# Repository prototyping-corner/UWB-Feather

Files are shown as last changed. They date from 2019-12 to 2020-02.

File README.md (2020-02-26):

# UWB Feather
  
OSHWA  

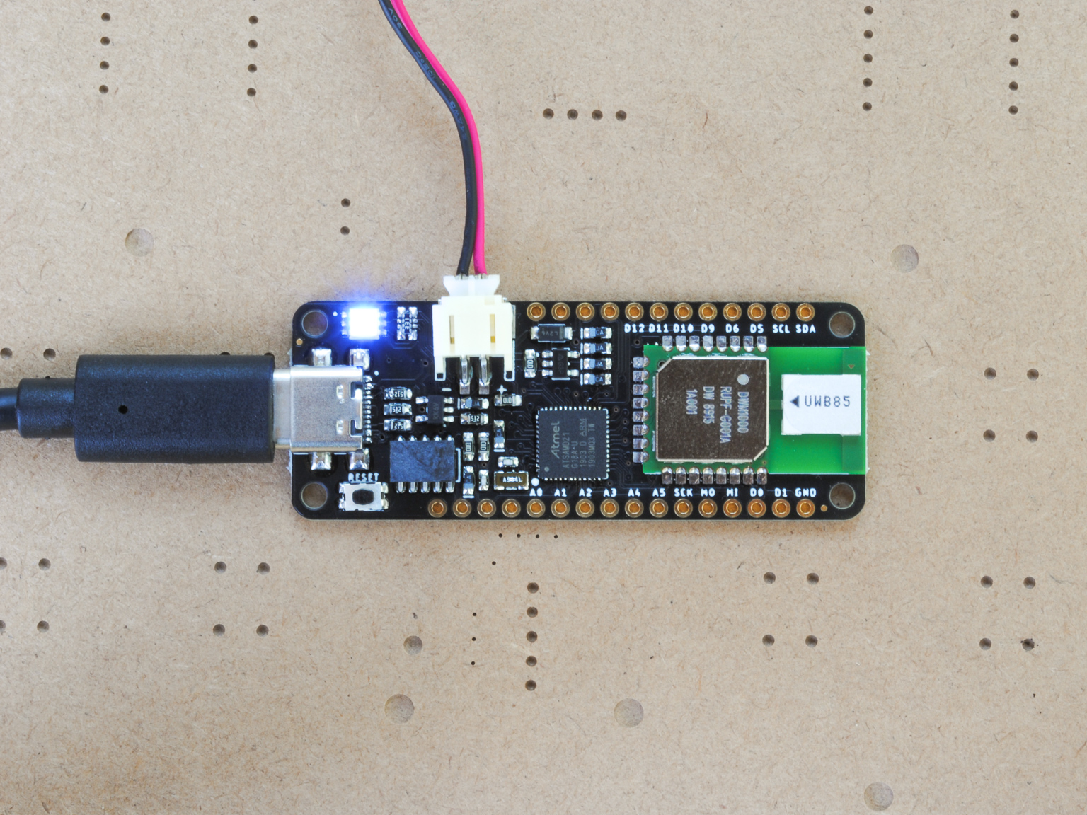
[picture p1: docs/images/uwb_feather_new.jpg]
Boards


The Ultra-WideBand Feather incorporates the Decawave DWM1000 module and an ATSAMD21 ARM Cortex M0 into the Adafruit feather form-factor. The DWM1000 module is an IEEE802.15.4-2011 UWB compliant wireless module capable of precision indoor positioning and high data rates, making this board perfect for robotics projects where localization is required.  

For full project details and documentation visit [prototypingcorner.io/projects/uwb-feather](prototypingcorner.io/projects/uwb-feather).

## Hardware
Licensed under the CERN OHL v1.2.  

Top  
Bottom  

## Firmware
Firmware providing in this repository is for testing the DWM1000 module and utilizes the [thotro/arduino-dw1000](https://github.com/thotro/arduino-dw1000) library. As this repository is no longer actively maintained, future development will focus on a new library.

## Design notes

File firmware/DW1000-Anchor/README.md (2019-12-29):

# DW1000 Anchor
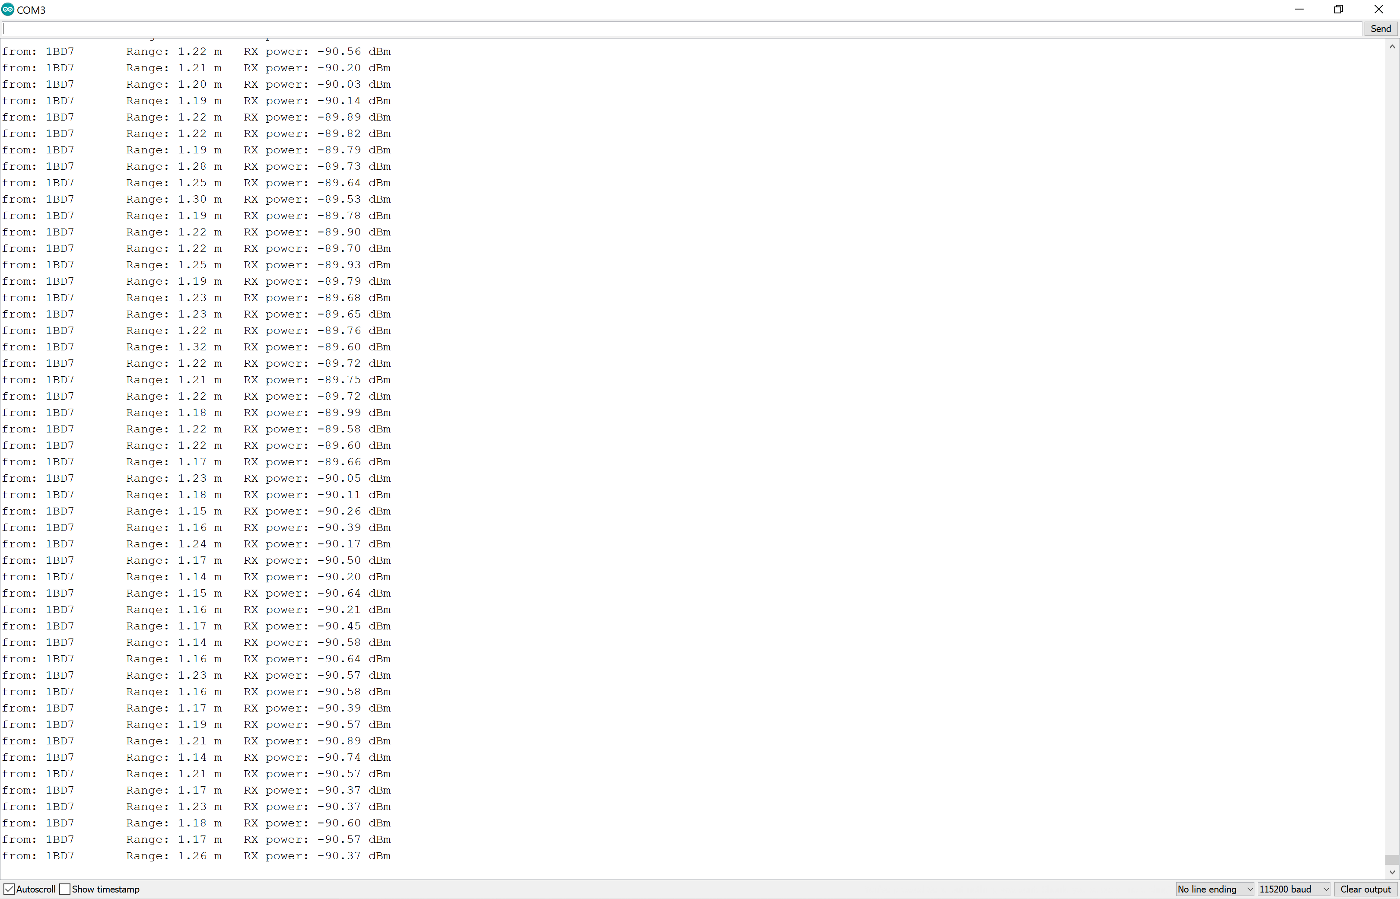
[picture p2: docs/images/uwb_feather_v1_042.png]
Ranging screenshot


Simple anchor mode for testing DWM1000 module. 
See [thotro/arduino-dw1000/examples/DW1000Ranging_TAG](https://github.com/thotro/arduino-dw1000/blob/master/examples/DW1000Ranging_TAG/DW1000Ranging_TAG.ino) for tag and set pins.

DW1000 library available from [thotro/arduino-dw1000](https://github.com/thotro/arduino-dw1000).

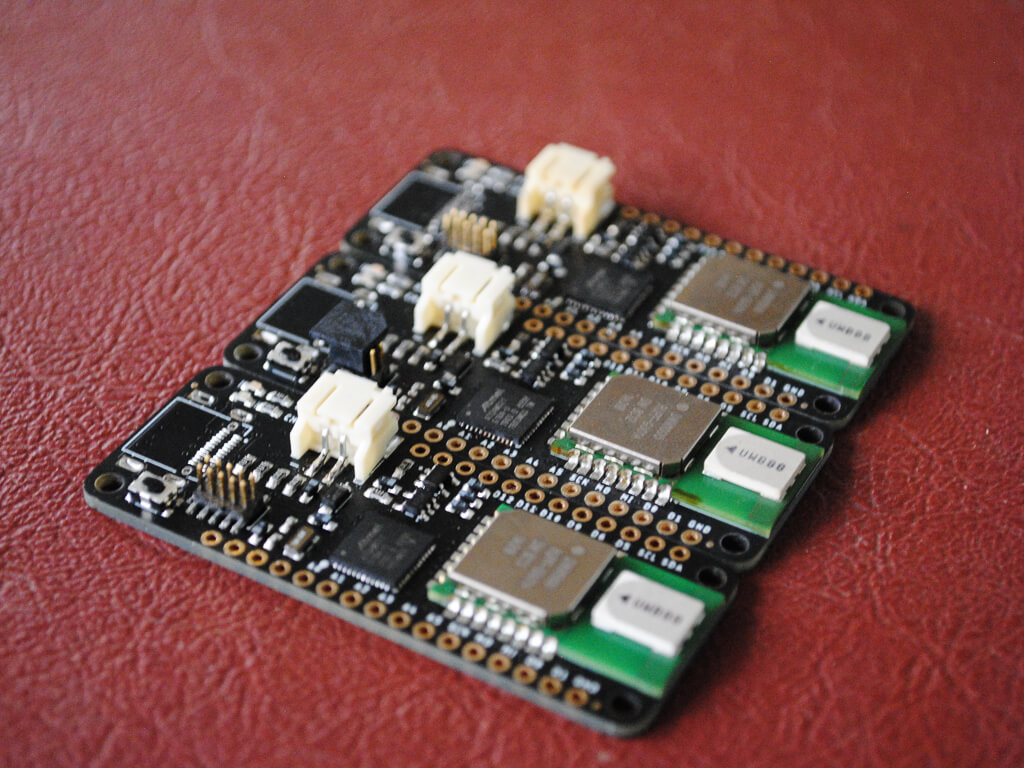
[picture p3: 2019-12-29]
docs/images/uwb_feather_v1_018.jpg

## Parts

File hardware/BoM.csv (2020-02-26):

Manufacturer Part Number | Manufacturer | Digi-Key Part Number | Customer Reference | Quantity | Description
S2B-PH-SM4-TB(LF)(SN) | JST Sales America Inc. | 455-1749-1-ND | CN1 | 1 | CONN HEADER SMD R/A 2POS 2MM
KMR241GLFS | C&K | 401-1431-1-ND | SW1 | 1 | SWITCH TACTILE SPST-NO 0.05A 32V
AP2112K-3.3TRG1 | Diodes Incorporated | AP2112K-3.3TRG1DICT-ND | U4 | 1 | IC REG LINEAR 3.3V 600MA SOT25
MBR120VLSFT1G | ON Semiconductor | MBR120VLSFT1GOSCT-ND | D1 | 1 | DIODE SCHOTTKY 20V 1A SOD123FL
ATSAMD21G18A-MU | Microchip Technology | ATSAMD21G18A-MU-ND | U1 | 1 | IC MCU 32BIT 256KB FLASH 48QFN
DWM1000 | Decawave Limited | 1479-1002-1-ND | U3 | 1 | RF TXRX MODULE 802.15.4 CHIP ANT
MCP73832T-2ACI/OT | Microchip Technology | MCP73832T-2ACI/OTCT-ND | U2 | 1 | IC CONTROLLR LI-ION 4.2V SOT23-5
RC0603FR-075K1L | Yageo | 311-5.10KHRCT-ND | R1, R2, R4, R6 | 4 | RES SMD 5.1K OHM 1% 1/10W 0603
RC0603FR-07100KL | Yageo | 311-100KHRCT-ND | R3, R5, R7, R9 | 4 | RES SMD 100K OHM 1% 1/10W 0603
TMCJ0J106MTRF | Vishay Sprague | 718-2355-1-ND | C5, C7, C8 | 3 | CAP TANT 10UF 20% 6.3V 0603
TMCJ1C105MTRF | Vishay Sprague | 718-2362-1-ND | C1, C4, C6, C9 | 4 | CAP TANT 1UF 20% 16V 0603
CC0402FRNPO9BN150 | Yageo | 311-1642-1-ND | C2, C3 | 2 | CAP CER 15PF 50V C0G/NPO 0402
FC-135 32.7680KA-A0 | EPSON | SER4077CT-ND | Y1 | 1 | CRYSTAL 32.7680KHZ 12.5PF SMT
ASMT-YTD7-0AA02 | Broadcom Limited | 516-3219-1-ND | D2 | 1 | LED RGB DIFFUSED 6PLCC SMD
20021121-00010C4LF | Amphenol ICC (FCI) | 609-3695-1-ND | J4 | 1 | CONN HEADER SMD 10POS 1.27MM
USB4110-GF-A | GCT | 2073-USB4110-GF-A-1-ND | J1 | 1 | CONN USB 2.0 TYPE-C R/A SMT
YC124-JR-07330RL | Yageo | YC124J-330CT-ND | R8 | 1 | RES ARRAY 4 RES 330 OHM 0804

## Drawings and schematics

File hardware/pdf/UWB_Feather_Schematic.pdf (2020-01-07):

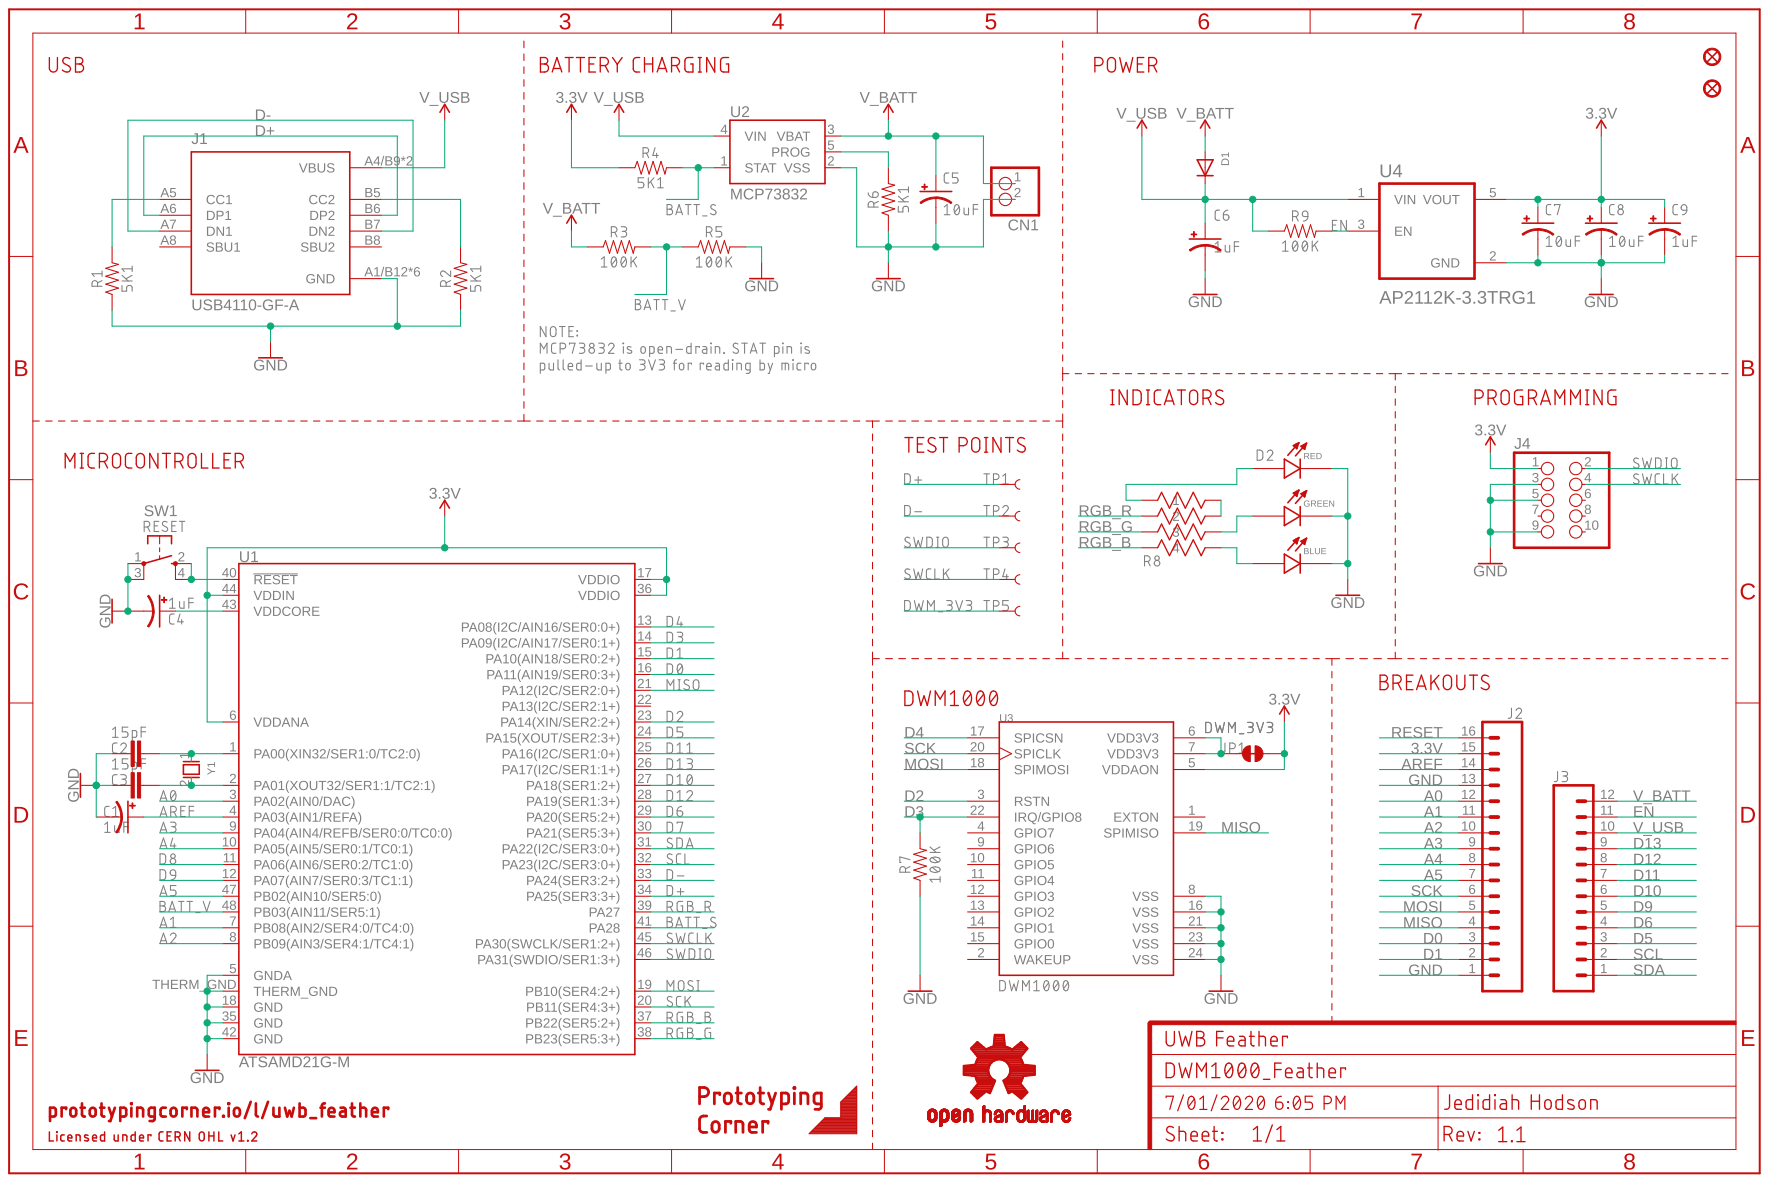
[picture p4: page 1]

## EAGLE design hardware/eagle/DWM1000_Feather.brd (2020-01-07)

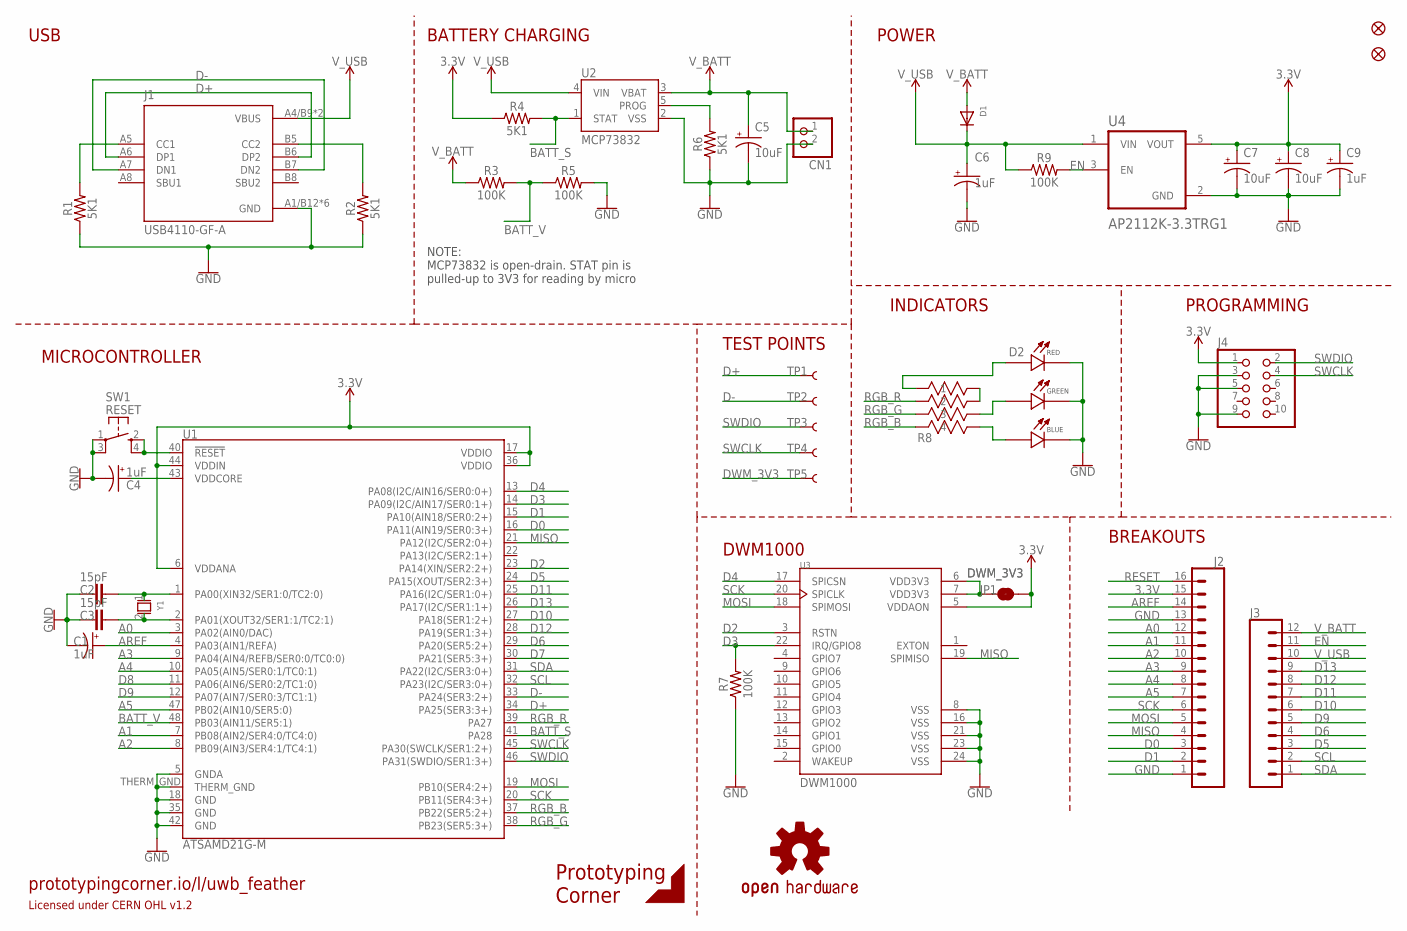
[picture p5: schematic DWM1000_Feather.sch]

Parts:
C1, C4, C6, C9: 1uF; 0603-POLAR
C2, C3: 15pF; 0402
C5, C7, C8: 10uF; 0603-POLAR
CN1: JST_2PIN-SMT-RA; JST-PH-2-SMT-RA
D1: DIODE_SOD-123FL; SOD-123FL
D2: ASMT-YTD7-0AA02; LED_ASMT-YTD7-0AA02
FD1, FD2: FIDUCIALUFIDUCIAL; FIDUCIAL-MICRO
J1: USB4110-GF-A; GCT_USB4110-GF-A
J2: CONN_161X16_NO_SILK; 1X16_NO_SILK
J3: CONN_12NO_SILK; 1X12_NO_SILK
J4: 20021221-00010C4LF
JP1: DWM_3V3; SMT-JUMPER_2_NC_TRACE_SILK
LOGO1: OSHW-LOGOS; OSHW-LOGO-S
R1, R2, R4, R6: 5K1; 0603
R3, R5, R7, R9: 100K; 0603
R8: YC124-JR-07330RL; YAG_YC124
SW1: SPST_TACT-KMR2; KMR2
TP1, TP2, TP3, TP4, TP5: TEST-POINT3; PAD.03X.03
U1: ATSAMD21G-M; QFN-48
U2: MCP73832; SOT23-5
U3: DWM1000; XCVR_DWM1000
U4: AP2112K-3.3TRG1; SOT95P285X140-5N
Y1: FC-135_32.7680KA-A0; XTAL_FC-135_32.7680KA-A0

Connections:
3.3V: C7.+ (1), C8.+ (1), C9.+ (1), J2.15, J4.1, JP1.2, R4.1, U1.6 (VDDANA), U1.17 (VDDIO), U1.36 (VDDIO), U1.44 (VDDIN), U3.5 (VDDAON), U4.5 (VOUT)
A0: J2.12, U1.3 (PA02(AIN0/DAC))
A1: J2.11, U1.7 (PB08(AIN2/SER4:0/TC4:0))
A2: J2.10, U1.8 (PB09(AIN3/SER4:1/TC4:1))
A3: J2.9, U1.9 (PA04(AIN4/REFB/SER0:0/TC0:0))
A4: J2.8, U1.10 (PA05(AIN5/SER0:1/TC0:1))
A5: J2.7, U1.47 (PB02(AIN10/SER5:0))
AREF: C1.+ (1), J2.14, U1.4 (PA03(AIN1/REFA))
BATT_S: R4.2, U1.41 (PA28), U2.1 (STAT)
BATT_V: R3.2, R5.1, U1.48 (PB03(AIN11/SER5:1))
D0: J2.3, U1.16 (PA11(AIN19/SER0:3+))
D1: J2.2, U1.15 (PA10(AIN18/SER0:2+))
D2: U1.23 (PA14(XIN/SER2:2+)), U3.3 (RSTN)
D3: R7.2, U1.14 (PA09(I2C/AIN17/SER0:1+)), U3.22 (IRQ/GPIO8)
D4: U1.13 (PA08(I2C/AIN16/SER0:0+)), U3.17 (SPICSN)
D5: J3.3, U1.24 (PA15(XOUT/SER2:3+))
D6: J3.4, U1.29 (PA20(SER5:2+))
D7: U1.30 (PA21(SER5:3+))
D8: U1.11 (PA06(AIN6/SER0:2/TC1:0))
D9: J3.5, U1.12 (PA07(AIN7/SER0:3/TC1:1))
D10: J3.6, U1.27 (PA18(SER1:2+))
D11: J3.7, U1.25 (PA16(I2C/SER1:0+))
D12: J3.8, U1.28 (PA19(SER1:3+))
D13: J3.9, U1.26 (PA17(I2C/SER1:1+))
D+: J1.A6 (DP1), J1.B6 (DP2), TP1.P$1, U1.34 (PA25(SER3:3+))
D-: J1.A7 (DN1), J1.B7 (DN2), TP2.P$1, U1.33 (PA24(SER3:2+))
DWM_3V3: JP1.1, TP5.P$1, U3.6 (VDD3V3), U3.7 (VDD3V3)
EN: J3.11, R9.2, U4.3 (EN)
GND: C1.- (2), C2.1, C3.1, C4.- (2), C5.- (2), C6.- (2), C7.- (2), C8.- (2), C9.- (2), CN1.2 (1), D2.1 (B_C), D2.2 (G_C), D2.3 (R_C), J1.A1/B12 (GND), J1.B1/A12 (GND), J1.S1 (GND), J1.S2 (GND), J1.S3 (GND), J1.S4 (GND), J2.1, J2.13, J4.3, J4.5, J4.9, R1.1, R2.1, R5.2, R6.1, R7.1, SW1.1, SW1.3 (P1), U1.5 (GNDA), U1.18 (GND), U1.35 (GND), U1.42 (GND), U1.THERM_GND, U2.2 (VSS), U3.8 (VSS), U3.16 (VSS), U3.21 (VSS), U3.23 (VSS), U3.24 (VSS), U4.2 (GND)
MISO: J2.4, U1.21 (PA12(I2C/SER2:0+)), U3.19 (SPIMISO)
MOSI: J2.5, U1.19 (PB10(SER4:2+)), U3.18 (SPIMOSI)
unnamed: D2.6 (B_A), R8.5
unnamed: D2.5 (G_A), R8.6
unnamed: R8.7, R8.8
unnamed: D2.4 (R_A), R8.1
unnamed: R6.2, U2.5 (PROG)
unnamed: J1.A5 (CC1), R1.2
unnamed: J1.B5 (CC2), R2.2
unnamed: C2.2, U1.1 (PA00(XIN32/SER1:0/TC2:0)), Y1.1
unnamed: C4.+ (1), U1.43 (VDDCORE)
unnamed: C3.2, U1.2 (PA01(XOUT32/SER1:1/TC2:1)), Y1.2
RESET: J2.16, SW1.2 (S), SW1.4 (S1), U1.40 (!RESET!)
RGB_B: R8.4, U1.37 (PB22(SER5:2+))
RGB_G: R8.3, U1.38 (PB23(SER5:3+))
RGB_R: R8.2, U1.39 (PA27)
SCK: J2.6, U1.20 (PB11(SER4:3+)), U3.20 (SPICLK)
SCL: J3.2, U1.32 (PA23(I2C/SER3:0+))
SDA: J3.1, U1.31 (PA22(I2C/SER3:0+))
SWCLK: J4.4, TP4.P$1, U1.45 (PA30(SWCLK/SER1:2+))
SWDIO: J4.2, TP3.P$1, U1.46 (PA31(SWDIO/SER1:3+))
V_BATT: C5.+ (1), CN1.1 (2), D1.A, J3.12, R3.1, U2.3 (VBAT)
V_USB: C6.+ (1), D1.C, J1.A4/B9 (VBUS), J1.B4/A9 (VBUS), J3.10, R9.1, U2.4 (VIN), U4.1 (VIN)

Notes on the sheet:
USB
BATTERY CHARGING
POWER
INDICATORS
BREAKOUTS
DWM1000
MICROCONTROLLER
PROGRAMMING
TEST POINTS
prototypingcorner.io/l/uwb_feather
NOTE: MCP73832 is open-drain. STAT pin is pulled-up to 3V3 for reading by micro
Prototyping Corner
Licensed under CERN OHL v1.2

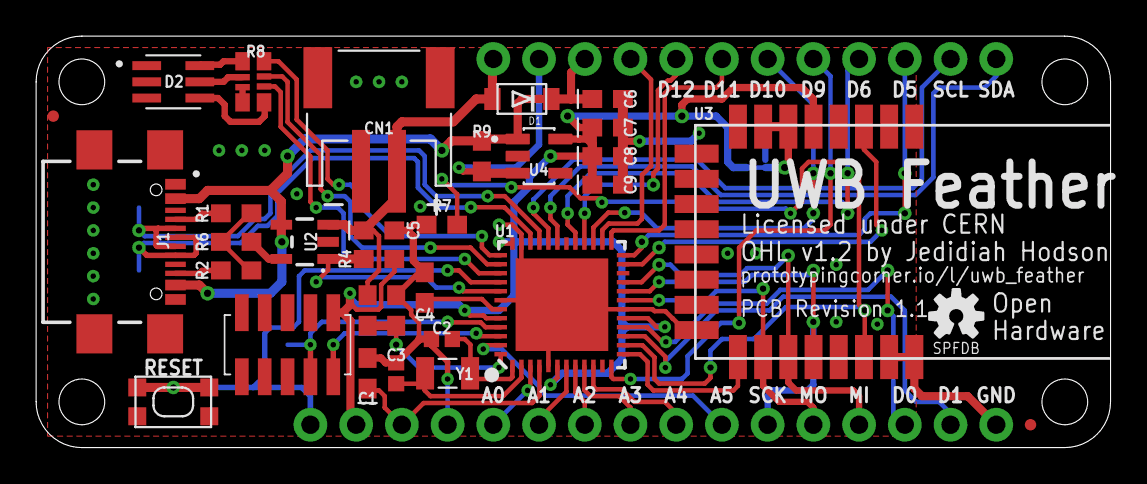
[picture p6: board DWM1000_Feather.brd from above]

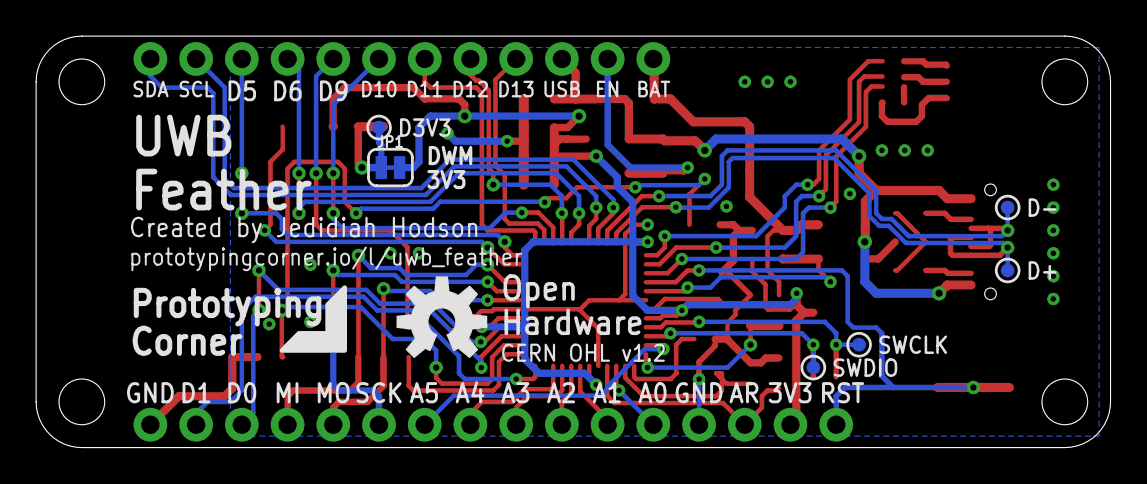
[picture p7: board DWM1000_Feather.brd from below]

Board: 2 copper layers, 59.7 x 22.9 mm, 41 parts (7 on the bottom side), 50 nets.

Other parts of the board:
U$2: OSHW-LOGO-M

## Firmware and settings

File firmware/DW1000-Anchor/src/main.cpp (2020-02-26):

/**
 * UWB Feather Ranging Demo
 * Configures device as. Derived from DW1000Ranging_ANCHOR & DW1000Ranging_TAG
 * example in thoro/arduino-dw1000
 * 
 * Visit prototypingcorner.io/projects/uwb-feather for more information
 */

#include <Arduino.h>
#include <SPI.h>
#include "DW1000Ranging.h"

#define DW1000_RST  2
#define DW1000_IRQ  3
#define DW1000_CS   4
#define LED         31

// Choose one
#define OP_TAG
//#define OP_ANCHOR

#ifdef OP_TAG
#include "tag.h"
#endif
#ifdef OP_ANCHOR
#include "anchor.h"
#endif

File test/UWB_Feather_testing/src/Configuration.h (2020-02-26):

#ifndef CONFIGURATION_H
#define CONFIGURATION_H
#include <Arduino.h>

#define DW1000_RST      2
#define DW1000_IRQ      3
#define DW1000_CS       4

#define LED_RED         26
#define LED_GREEN       31
#define LED_BLUE        30

#define BATTERY_VOLT    25
#define BATTERY_CHARGE  27

#endif

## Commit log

2019-12-29 Added parts BoM
    [BoM.csv]
2019-12-29 V1 Eagle CAD files
    [DWM1000_Feather.brd, DWM1000_Feather.sch]
2020-01-06 Version 1.1 update. BRD is INCOMPLETE
    [DWM1000_Feather.brd, DWM1000_Feather.sch]
2020-01-07 Updated for version 1.1
    [BoM.csv, DWM1000_Feather.brd, DWM1000_Feather.sch]
2020-01-07 Added board renders
2020-01-07 Updated U2 BoM item
    [BoM.csv]
2020-02-26 Lots of misc. changes
    [Configuration.h]

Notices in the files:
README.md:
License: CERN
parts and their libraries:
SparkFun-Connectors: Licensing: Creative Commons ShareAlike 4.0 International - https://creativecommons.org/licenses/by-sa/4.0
